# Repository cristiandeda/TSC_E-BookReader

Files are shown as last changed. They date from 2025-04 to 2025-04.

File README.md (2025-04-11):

# TSC_E-BookReader

## Diagrama bloc:
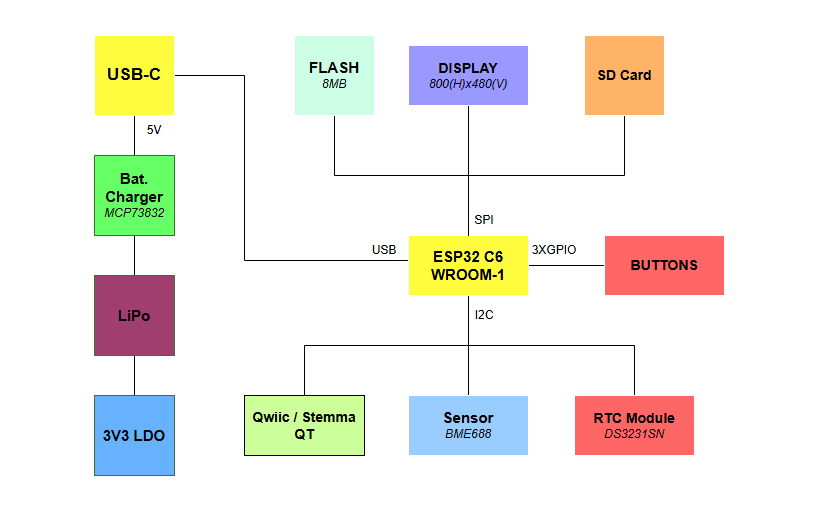
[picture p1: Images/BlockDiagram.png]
diagram


## Pasi de implementare:

- Am creat **schema electrica** pe baza celei atasate in cerinta, folosind biblioteca `DeskAssistant`
- Am creat apoi **PCB**-ul:
    - am modificat dimensiunile PCB-ului pentru a corespunde cu cele descrise in cerinta
    -  am plasat componentele in functie de schema electrica, grupandu-le pe baza 'functionalitatii'
    -  am decupat PCB-ul conform fisierului atasat in enunt
    -  am modificat denumirile *test-pad-urilor* - *TP* in functie de semnalele pe care le poarta
    -  am facut autorutare cu dimensiunile traseelor de alimentare precizate in enunt (`VBUS`, `VUSB`, `VBAT`, `3V3`, `EPD_3V3` si `EPD_3V3_C` cu *CopperWidth* de minimum **0.3 mm**, iar restul cu *CopperWidth* de minimum **0.15 mm**)
    -  am trasat planurile de masa (*top* si *bottom*)
- Am introdus modelele **3D**:
    - am descarcat modelele 3D corespunzatoare de pe [Component Search Engine](https://componentsearchengine.com/)
    - am editat fiecare componenta, adaugandu-i modelul 3D pe care l-am pozitionat conform *pinilor* / *footprint-ului*
- Am desenat modelele **3D** pentru *baterie*, *ecran* si *test-pad-uri* tinand cont de dimensiuni
- Am adaugat toate piesele (*placuta*, *ecranul*, *bateria* si *carcasa*) obtinand produsul final

## Descriere functionalitate hardware:

### 1. Alimentare și Protecție (USB-C & ESD)
- **Conector USB-C**: permite alimentarea plăcii și comunicarea de date.
- **PFMF.050.1**, **TVS diode (D1)**: oferă protecție la supratensiuni și descărcări electrostatice.
- **IC1**: convertește tensiunea de intrare (5V) la 3.3V, necesară pentru alimentarea circuitelor logice (ESP32, senzori, etc.).

### 2. Control Alimentare Baterie
- **MCP73831** este un controler de încărcare pentru baterii Li-Po.
- **C1, C2** filtrează zgomotele pe linia de alimentare.
- Permite alimentarea sistemului din baterie reîncărcabilă și oferă protecție la supraîncărcare/descărcare.

### 3. Nivel Încărcare Baterie
- **MAX17048** măsoară nivelul de încărcare al bateriei.
- Comunicarea se face prin magistrala I2C (SCL/SDA), comună cu alți senzori.
- Permite afișarea nivelului bateriei pe ecran sau transmiterea sa prin rețea.

### 4. Afișaj E-Paper
- **Header E-Paper** conectează un afișaj de tip E-Ink.
- **Driverul de semnal (MBR0530, L1, Q3)** controlează alimentarea și semnalele de comutare pentru afișaj.
- Selectarea tipului de ecran se face cu jumperul **S1**.
- Afișajul e-paper este ideal pentru consum redus de energie.

### 5. Modul RTC (Ceas în timp real)
- **DS3231SN** menține ora exactă, chiar și când placa este oprită.
- Funcționează pe I2C și are o baterie de rezervă.

### 6. Senzor Ambiental (BME688)
- Măsoară temperatură, umiditate, presiune și calitatea aerului.
- Se conectează la ESP32 prin I2C.

### 7. Memorie NOR Flash externă (64MB)
- **W25Q512JVEIQ** este o memorie SPI folosită pentru stocare extinsă (ex: cărți, imagini, date).
- Conectată la ESP32 pe interfață SPI (IO4–IO7).
- Permite stocarea persistentă a fișierelor.

### 8. Cititor Card SD
- Slot SD conectat prin SPI (IO8–IO11).
- Permite acces la fișiere externe, jurnalizare sau încărcare de date din card.

### 9. ESP32-C6 - Microcontroller Principal
- Conectează toate perifericele și controlează logica sistemului.
- Suportă Wi-Fi 6, BLE 5.2 și Zigbee/Thread.
- Are GPIO configurate pentru SPI, I2C, UART și control E-Paper.
- Este nucleul care rulează software-ul aplicației.

### 10. Protecții ESD pe SPI & Qwiic
- Diodă **TVS** și rezistențe pe liniile SPI/Qwiic pentru protecție la ESD.
- Asigură durabilitate mai mare în aplicații reale.

### 11. Butoane - Reset & Boot
- Buton **RESET**: Repornește ESP32.
- Buton **BOOT**: Permite intrarea în mod de boot pentru programare.
- Ambele conectate la pini critici (EN, IO0).

### 12. Interfață Qwiic / Stemma QT
- Conector I2C standard (JST-SH 4 pini).
- Permite adăugarea rapidă de senzori sau module adiționale compatibile.

### 13. Test Pads
- Paduri expuse pentru GPIO-uri esențiale.
- Permit depanarea, măsurători și extinderea funcționalității.

---

## Descrierea pinilor ESP32-C6:

| Pin ESP32-C6 | Nume Semnal | Componentă Asociată | Scop / Funcție |
|---|---|---|---|
| GND | GND | Toate componentele | Masă comună pentru alimentare și semnal. |
| EN | Enable | Buton Reset | Resetează microcontrollerul la apăsare. |
| IO0 | GPIO0 | Buton BOOT | Intrare în modul de boot la apăsare. |
| IO1 | GPIO1 | Test Pad TP11 | Test/debug sau I/O general. |
| IO2 | GPIO2 | Test Pad TP12 | Test/debug sau I/O general. |
| IO3 | GPIO3 | Test Pad TP13 | Test/debug sau I/O general. |
| IO4 | GPIO4 | SPI Flash (CS) | Chip Select pentru memoria NOR Flash externă. |
| IO5 | GPIO5 | SPI Flash (CLK) | Clock SPI pentru memoria NOR Flash externă. |
| IO6 | GPIO6 | SPI Flash (MISO) | Data Out din NOR Flash spre ESP32. |
| IO7 | GPIO7 | SPI Flash (MOSI) | Data In către NOR Flash de la ESP32. |
| IO8 | GPIO8 | SD Card (CS) | Chip Select pentru card SD. |
| IO9 | GPIO9 | SD Card (CLK) | Clock SPI pentru card SD. |
| IO10 | GPIO10 | SD Card (MISO) | Date de pe card SD către ESP32. |
| IO11 | GPIO11 | SD Card (MOSI) | Date de la ESP32 către card SD. |
| IO12 | GPIO12 | E-Paper Header | Semnal pentru ecran E-Paper (ex: BUSY, RST etc.). |
| IO13 | GPIO13 | E-Paper Header | Semnal pentru ecran E-Paper. |
| IO14 | GPIO14 | E-Paper Header | Semnal pentru ecran E-Paper. |
| IO15 | GPIO15 | E-Paper Header | Semnal pentru ecran E-Paper. |
| IO16 | GPIO16 | SCL (RTC & BME688) | I2C Clock comun pentru RTC și senzor de mediu. |
| IO17 | GPIO17 | SDA (RTC & BME688) | I2C Data comun pentru RTC și senzor de mediu. |
| IO18 | GPIO18 | UART_RX (Qwiic/Debug) | Recepție serială (debug sau Qwiic/StemMA). |
| IO19 | GPIO19 | UART_TX (Qwiic/Debug) | Transmisie serială (debug sau Qwiic/StemMA). |

## Bill of Materials (BOM):

| Componenta | Link | Datasheet |
|---|---|---|
| ESP32-C6-WROOM-1-N8 | [Link](https://ro.mouser.com/ProductDetail/Espressif-Systems/ESP32-C6-WROOM-1-N8?qs=8Wlm6%252BaMh8ST02Gmwp74cw%3D%3D) | [Datasheet](https://ro.mouser.com/datasheet/2/891/Espressif_ESP32_C6_WROOM_1__Datasheet_V0_1_PRELIMI-3239987.pdf) |
| 112A-TAAR-R03_ATTEND | [Link](https://www.digikey.ro/ro/products/detail/attend-technology/112A-TAAR-R03/17633923) | [Datasheet](https://www.attend.com.tw/data/download/file/112A-TAAR-R03_Spec.pdf) |
| ADAFRUIT_LEDCHIP-LED0603 | [Link](https://www.snapeda.com/parts/KP-1608SURCK/Kingbright/view-part/?ref=search&t=LED%200603) | [Datasheet](https://www.snapeda.com/parts/KP-1608SURCK/Kingbright/datasheet/) |
| ESP32_WROVER_EAGLE-LTSPICE_RR0402 | [Link](https://www.snapeda.com/parts/RC0402FR-07226RL/Yageo/view-part/) | [Datasheet](https://www.snapeda.com/parts/RC0402FR-07226RL/Yageo/datasheet/) |
| ESP32_WROVER_EAGLE-LTSPICE_CC0402 | [Link](https://componentsearchengine.com/part-view/CC0402MRX5R5BB106/YAGEO) | [Datasheet](https://componentsearchengine.com/Datasheets/2/CC0402MRX5R5BB106.pdf) |
| RCL_CPOL-EUCT3528 | [Link](https://ro.mouser.com/ProductDetail/Vishay-Sprague/TR3B106K025C1300?qs=jCGqFXxTmLdffnuDkXzk1g%3D%3D) | [Datasheet](https://www.vishay.com/docs/40080/tr3.pdf) |
| ESP32_WROVER_SPARKFUN-DISCRETESEMI_MOSFET_PCH-DMG2305UX-7 | [Link](https://ro.mouser.com/ProductDetail/Diodes-Incorporated/DMG2305UX-7?qs=L1DZKBg7t5F%2FNBHrjfxC%252Bg%3D%3D) | [Datasheet](https://www.diodes.com/assets/Datasheets/DMG2305UX.pdf) |
| 744043680IND_4828-WE-TPC_WRE | [Link](https://www.digikey.sg/en/products/detail/w%C3%BCrth-elektronik/744043680/1638515) | [Datasheet](https://www.we-online.com/components/products/datasheet/744043680.pdf) |
| BD5229G-TR | [Link](https://ro.mouser.com/ProductDetail/ROHM-Semiconductor/BD5229G-TR?qs=4kLU8WoGk0vvnhrrYwdszw%3D%3D) | [Datasheet](https://fscdn.rohm.com/en/products/databook/datasheet/ic/power/voltage_detector/bd52xxg-e.pdf) |
| ESP32_WROVER_BME680_BME680 | [Link](https://ro.mouser.com/ProductDetail/Bosch-Sensortec/BME680?qs=v271MhAjFHjo0yA%2FC4OnDQ%3D%3D) | [Datasheet](https://ro.mouser.com/datasheet/2/783/BST_BME680_DS001-1509608.pdf) |
| BUTTON_CUSYOMV1 | [Link](https://ro.mouser.com/ProductDetail/Panasonic/EVQ-P7M01P?qs=rJ%252BziJWpysz0sJAzuCybtw%3D%3D) | [Datasheet](https://industry.panasonic.com/global/en/downloads/?file_cd=402906&tab=catalog&series_cd=3457) |
| CPH3225A | [Link](https://ro.mouser.com/ProductDetail/Seiko-Semiconductors/CPH3225A?qs=3etwrb1wR%252BhUOph6lAO7eg%3D%3D) | [Datasheet](https://ro.mouser.com/datasheet/2/360/Seiko_Instruments_MicroBattery_E_20230330_2024Jan_-3561061.pdf) |
| DS3231SN# | [Link](https://ro.mouser.com/ProductDetail/Analog-Devices-Maxim-Integrated/DS3231SN?qs=1eQvB6Dk1vhUlr8%2FOrV0Fw%3D%3D) | [Datasheet](https://ro.mouser.com/datasheet/2/609/DS3231-3421123.pdf) |
| ESP32C6_VARISTORCN1812 | [Link](https://eu.mouser.com/ProductDetail/KEMET/VC1812L501R008?qs=jj7GbYRQuOa1j1%2F3gPpdvQ%3D%3D) | [Datasheet](https://eu.mouser.com/datasheet/2/447/KEM_V0002_VC-3316862.pdf) |
| ESP32_WROVER_AVX---SD0805S020S1R0_AVX_SD0805S020S1R0_0_0AVX_SD0805S020S1R0_0_0 | [Link](https://eu.mouser.com/ProductDetail/KYOCERA-AVX/SD0805S020S1R0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) | [Datasheet](https://eu.mouser.com/datasheet/2/40/schottky-3165252.pdf) |
| FH34SRJ-24S-0.5SH_99_ | [Link](https://eu.mouser.com/ProductDetail/Hirose-Connector/FH34SRJ-24S-05SH99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) | [Datasheet](https://eu.mouser.com/datasheet/2/185/FH34SRJ_24S_0_5SH_99__CL0580_1255_6_99_2DDrawing_0-1615044.pdf) |
| MAX17048G+T10 | [Link](https://eu.mouser.com/ProductDetail/Analog-Devices-Maxim-Integrated/MAX17048G+T10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) | [Datasheet](https://eu.mouser.com/datasheet/2/609/MAX17048_MAX17049-3469099.pdf) |
| MBR0530 | [Link](https://eu.mouser.com/ProductDetail/Micro-Commercial-Components-MCC/MBR0530-TP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) | [Datasheet](https://eu.mouser.com/datasheet/2/258/MBR0520_MBR0580_SOD123_-2492194.pdf) |
| ESP32_WROVER_SPARKFUN-IC-POWER_MCP73831 | [Link](https://ro.mouser.com/ProductDetail/Microchip-Technology/MCP73831-2DCI-MC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) | [Datasheet](https://ro.mouser.com/datasheet/2/268/MCP73831_Family_Data_Sheet_DS20001984H-3441711.pdf) |
| PGB1010603MR | [Link](https://ro.mouser.com/ProductDetail/Littelfuse/PGB1010603MR?qs=gu7KAQ731URLg4GSnNNN7Q%3D%3D) | [Datasheet](https://www.littelfuse.com/assetdocs/pulseguard-esd-suppressors-pgb1-datasheet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) |
| QWIIC_CONNECTORJS-1MM | [Link](https://www.sparkfun.com/qwiic-jst-connector-smd-4-pin-vertical.html) | [Datasheet](https://www.jst-mfg.com/product/pdf/eng/eSH.pdf?5ec58813d214e) |
| SAMACSYS_PARTS_USB4110-GF-A | [Link](https://eu.mouser.com/ProductDetail/GCT/USB4110-GF-A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) | [Datasheet](https://eu.mouser.com/datasheet/2/837/GCT_USB4110_Product_Drawing___20k_cycles-3455479.pdf) |
| SI1308EDL-T1-GE3 | [Link](https://eu.mouser.com/ProductDetail/Vishay-Semiconductors/SI1308EDL-T1-GE3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) | [Datasheet](https://www.vishay.com/docs/63399/si1308edl.pdf) |
| USBLC6-2SC6Y | [Link](https://eu.mouser.com/ProductDetail/STMicroelectronics/USBLC6-2SC6Y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) | [Datasheet](https://eu.mouser.com/datasheet/2/389/usblc6_2sc6y-1852505.pdf) |
| SJ | [Link](https://grabcad.com/library/solder-jumpers-1) | [Datasheet]() |
| W25Q512JVEIQ | [Link](https://eu.mouser.com/ProductDetail/Winbond/W25Q512JVEIQ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) | [Datasheet](https://eu.mouser.com/datasheet/2/949/Winbond_W25Q512JV_Datasheet-3240039.pdf) |
| XC6220A331MR-G | [Link](https://eu.mouser.com/ProductDetail/Torex-Semiconductor/XC6220A331MR-G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) | [Datasheet](https://eu.mouser.com/datasheet/2/760/xc6220-3371556.pdf) |

## Probleme:

- Am aprobat 2 erori tip *SMD-Hole* la rutarea *PCB-ului*
- Am aprobat erorile de tip *part X has no value* sau *pin X connected to Y* ce apareau dupa rularea *ERC-ului* in schematic
- Pentru *Test-pad-uri* am creat eu un model 3D cilindric, deoarece nu am gasit model pe internet

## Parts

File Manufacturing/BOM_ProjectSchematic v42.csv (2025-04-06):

Qty | Value | Device | Package | Parts | Description | ARROW_PART_NUMBER | ARROW_PRICE-STOCK | AVAILABILITY | CENTROID_NOT_SPECIFIED | CHECK_PRICES | COPYRIGHT | DATASHEET | DESCRIPTION | DIGIKEY_DESCRIPTION | DIGIKEY_PART_NUMBER | HEIGHT | LEAD_FREE | MANUFACTURER_NAME | MANUFACTURER_PART_NUMBER | MF | MFR_NAME | MOUSER_PART_NUMBER | MOUSER_PRICE-STOCK | MOUSER_TESTING_PART_NUMBER | MOUSER_TESTING_PRICE-STOCK | MP | MPN | PACKAGE | POPULARITY | PREFIX | PRICE | PROD_ID | PURCHASE-URL | ROHS | SNAPEDA_LINK | SPICEMODEL | SPICEPREFIX | TEMPERATURE_RANGE_HIGH | TEMPERATURE_RANGE_LOW | TP_SIGNAL_NAME | VALUE
1 |  | ADAFRUIT_LEDCHIP-LED0603 | ADAFRUIT_CHIP-LED0603 | CHG_LED | LED
1 |  | SJ | SJ | SJ1 | SMD solder JUMPER |  |  |  |  |  |  |  |  |  |  |  |  |  |  |  |  |  |  |  |  |  |  |  | 3
1 | 0.1uF/50V | ESP32_WROVER_EAGLE-LTSPICE_CC0402 | ESP32_WROVER_EAGLE-LTSPICE_C0402 | EPD_C5 | CAPACITOR, European symbol |  |  |  |  |  |  |  |  |  |  |  |  |  |  |  |  |  |  |  |  |  |  |  |  |  |  |  |  |  |  | NONE | C
1 | 0.47 | ESP32_WROVER_EAGLE-LTSPICE_RR0402 | ESP32_WROVER_EAGLE-LTSPICE_R0402 | R3 | RESISTOR, European symbol |  |  |  |  |  |  |  |  |  |  |  |  |  |  |  |  |  |  |  |  |  |  |  |  |  |  |  |  |  |  | NONE | R
1 | 100K | ESP32_WROVER_EAGLE-LTSPICE_RR0402 | ESP32_WROVER_EAGLE-LTSPICE_R0402 | R1_PWRUSB | RESISTOR, European symbol |  |  |  |  |  |  |  |  |  |  |  |  |  |  |  |  |  |  |  |  |  |  |  |  |  |  |  |  |  |  | NONE | R
8 | 100nF | ESP32_WROVER_EAGLE-LTSPICE_CC0402 | ESP32_WROVER_EAGLE-LTSPICE_C0402 | C1, C2, C4_USB, C6, C8, C9, C10, C_DELAY | CAPACITOR, European symbol |  |  |  |  |  |  |  |  |  |  |  |  |  |  |  |  |  |  |  |  |  |  |  |  |  |  |  |  |  |  | NONE | C
1 | 100uF TANT | RCL_CPOL-EUCT3528 | RCL_CT3528 | C3 | POLARIZED CAPACITOR, European symbol |  |  |  |  |  |  |  |  |  |  |  |  |  |  |  |  |  |  |  |  |  |  |  | 0 |  |  |  |  |  |  |  | C
16 | 10K | ESP32_WROVER_EAGLE-LTSPICE_RR0402 | ESP32_WROVER_EAGLE-LTSPICE_R0402 | R1, R1_PINH, R1_PINH1, R2-PINH, R2-PINH1, R4, R5, R6, R7, R8, R9, R10, R_BOOT, R_CHANGE, R_CL1, R_RESET | RESISTOR, European symbol |  |  |  |  |  |  |  |  |  |  |  |  |  |  |  |  |  |  |  |  |  |  |  |  |  |  |  |  |  |  | NONE | R
1 | 10uF | ESP32_WROVER_EAGLE-LTSPICE_CC0402 | ESP32_WROVER_EAGLE-LTSPICE_C0402 | C7 | CAPACITOR, European symbol |  |  |  |  |  |  |  |  |  |  |  |  |  |  |  |  |  |  |  |  |  |  |  |  |  |  |  |  |  |  | NONE | C
1 | 112A-TAAR-R03_ATTEND | 112A-TAAR-R03_ATTEND | 112ATAARR03ATTEND | J4 | Micro SD Card Socket, Push-Push Type, Top Mount, SMT, H=1.83mm, 10u |  |  |  |  |  |  |  | Micro SD Card Socket | Push-Push Type | Top Mount | SMT | H=1.83mm | 10u |  |  | 1.9mm |  | ATTEND | 112A-TAAR-R03 ATTEND
1 | 15 | ESP32_WROVER_EAGLE-LTSPICE_RR0402 | ESP32_WROVER_EAGLE-LTSPICE_R0402 | R_CAPACITOR | RESISTOR, European symbol |  |  |  |  |  |  |  |  |  |  |  |  |  |  |  |  |  |  |  |  |  |  |  |  |  |  |  |  |  |  | NONE | R
1 | 1uF | ESP32_WROVER_EAGLE-LTSPICE_CC0402 | ESP32_WROVER_EAGLE-LTSPICE_C0402 | C5 | CAPACITOR, European symbol |  |  |  |  |  |  |  |  |  |  |  |  |  |  |  |  |  |  |  |  |  |  |  |  |  |  |  |  |  |  | NONE | C
9 | 1uF/50V | ESP32_WROVER_EAGLE-LTSPICE_CC0402 | ESP32_WROVER_EAGLE-LTSPICE_C0402 | EPD_C1, EPD_C2, EPD_C6, EPD_C7, EPD_C8, EPD_C9, EPD_C10, EPD_C11, EPD_C12 | CAPACITOR, European symbol |  |  |  |  |  |  |  |  |  |  |  |  |  |  |  |  |  |  |  |  |  |  |  |  |  |  |  |  |  |  | NONE | C
1 | 2.2 | ESP32_WROVER_EAGLE-LTSPICE_RR0402 | ESP32_WROVER_EAGLE-LTSPICE_R0402 | R2 | RESISTOR, European symbol |  |  |  |  |  |  |  |  |  |  |  |  |  |  |  |  |  |  |  |  |  |  |  |  |  |  |  |  |  |  | NONE | R
1 | 200 | ESP32_WROVER_EAGLE-LTSPICE_RR0402 | ESP32_WROVER_EAGLE-LTSPICE_R0402 | R1_BAT | RESISTOR, European symbol |  |  |  |  |  |  |  |  |  |  |  |  |  |  |  |  |  |  |  |  |  |  |  |  |  |  |  |  |  |  | NONE | R
2 | 20V/4.2A/52mO/1.4W | ESP32_WROVER_SPARKFUN-DISCRETESEMI_MOSFET_PCH-DMG2305UX-7 | ESP32_WROVER_SPARKFUN-DISCRETESEMI_SOT23-3 | Q1, Q2 | P-channel MOSFETs |  |  |  |  |  |  |  |  |  |  |  |  |  |  |  |  |  |  |  |  |  |  |  |  |  |  | TRAN-14388 |  |  |  |  |  |  |  |  | 20V/4.2A/52mO/1.4W
1 | 2K | ESP32_WROVER_EAGLE-LTSPICE_RR0402 | ESP32_WROVER_EAGLE-LTSPICE_R0402 | R2_BAT | RESISTOR, European symbol |  |  |  |  |  |  |  |  |  |  |  |  |  |  |  |  |  |  |  |  |  |  |  |  |  |  |  |  |  |  | NONE | R
5 | 4.7uF | ESP32_WROVER_EAGLE-LTSPICE_CC0402 | ESP32_WROVER_EAGLE-LTSPICE_C0402 | C1_BAT, C1_BAT1, C1_BAT2, C2_BAT, C5_USB | CAPACITOR, European symbol |  |  |  |  |  |  |  |  |  |  |  |  |  |  |  |  |  |  |  |  |  |  |  |  |  |  |  |  |  |  | NONE | C
1 | 4.7uF/25V | ESP32_WROVER_EAGLE-LTSPICE_CC0402 | ESP32_WROVER_EAGLE-LTSPICE_C0402 | C4 | CAPACITOR, European symbol |  |  |  |  |  |  |  |  |  |  |  |  |  |  |  |  |  |  |  |  |  |  |  |  |  |  |  |  |  |  | NONE | C
1 | 5K1 | ESP32_WROVER_EAGLE-LTSPICE_RR0402 | ESP32_WROVER_EAGLE-LTSPICE_R0402 | R2-USB1 | RESISTOR, European symbol |  |  |  |  |  |  |  |  |  |  |  |  |  |  |  |  |  |  |  |  |  |  |  |  |  |  |  |  |  |  | NONE | R
1 | 5k1 | ESP32_WROVER_EAGLE-LTSPICE_RR0402 | ESP32_WROVER_EAGLE-LTSPICE_R0402 | R2-USB | RESISTOR, European symbol |  |  |  |  |  |  |  |  |  |  |  |  |  |  |  |  |  |  |  |  |  |  |  |  |  |  |  |  |  |  | NONE | R
1 | 68uH | 744043680IND_4828-WE-TPC_WRE | IND_4828-WE-TPC_WRE | L1 |  |  |  |  |  |  | Copyright (C) 2024 Ultra Librarian. All rights reserved. |  |  |  |  |  |  |  | 744043680 |  | Wurth Electronics
1 | BD5229G-TR | BD5229G-TR | SOT95P280X125-5N | IC1 | Voltage Detector with Adjustable Delay Time: CMOS processes are utilized to develop high precision, low current consumption CMOS reset ICs that allow arbitrary setting of the delay time. The extensive lineup includes both Nch Open Drain and CMOS output types in a wide range of detection voltages (from 2.3V to 6.0V, in 0.1V steps), enabling selection of the ideal solution based on customer requirements. In addition, the entire series is of course both lead-free and RoHS-compliant. |  |  |  |  |  |  |  | Voltage Detector with Adjustable Delay Time: CMOS processes are utilized to develop high precision | low current consumption CMOS reset ICs that allow arbitrary setting of the delay time. The extensive lineup includes both Nch Open Drain and CMOS output types in a wide range of detection voltages (from 2.3V to 6.0V | in 0.1V steps) | enabling selection of the ideal solution based on customer requirements. In addition | the entire series is of course both lead-free and RoHS-compliant. |  |  | 1.25mm |  | ROHM Semiconductor | BD5229G-TR |  |  | 755-BD5229G-TR | https://www.mouser.co.uk/ProductDetail/ROHM-Semiconductor/BD5229G-TR?qs=4kLU8WoGk0vvnhrrYwdszw%3D%3D
1 | BME688 | ESP32_WROVER_BME680_BME680 | ESP32_WROVER_BME680_PSON80P300X300X100-8N | SENSOR2 | Integrated Environmental Unit |  |  | Unavailable |  |  |  |  | Integrated Environmental Unit |  |  |  |  |  |  | Bosch Sensortec |  |  |  |  |  | BME680 |  | LGA-8 Bosch Tools |  |  | None
3 | BUTTON_CUSYOMV1 | BUTTON_CUSYOMV1 | MYBUTTON | BOOT_BUTTON, CHANGE_BUTTON, RESET_BUTTON
1 | CPH3225A | CPH3225A | CAPCP3225X100N | C10_SUPERCAP | Cap 0.011F 3.3V 1210 Flat Check availability |  |  | Not in stock |  | https://www.snapeda.com/parts/CPH3225A/Seiko+Instruments/view-part/?ref=eda |  |  | 11 mF (EDLC) Supercapacitor 3.3 V 1210 (3225 Metric) - - |  |  |  |  |  |  | Seiko Instruments |  |  |  |  |  | CPH3225A |  | 1210 Seiko |  |  | None |  | https://www.snapeda.com/api/url_track_click_mouser/?unipart_id=562593&manufacturer=Seiko Instruments&part_name=CPH3225A&search_term=None |  | https://www.snapeda.com/parts/CPH3225A/Seiko+Instruments/view-part/?ref=snap
1 | DS3231SN# | DS3231SN# | SOIC127P1032X265-16N | U3 | Real Time Clock Serial 16-Pin SOIC W T/R Check availability |  |  | In Stock |  | https://www.snapeda.com/parts/DS3231SN%23/Analog+Devices/view-part/?ref=eda |  |  | Extremely Accurate I²C-Integrated RTC/TCXO/Crystal |  |  |  |  |  |  | Analog Devices |  |  |  |  |  | DS3231SN# |  | SOIC-16 Maxim |  |  | None |  | https://www.snapeda.com/api/url_track_click_mouser/?unipart_id=99048&manufacturer=Analog Devices&part_name=DS3231SN#&search_term=None |  | https://www.snapeda.com/parts/DS3231SN%23/Analog+Devices/view-part/?ref=snap
1 | ESP32-C6-WROOM-1-N8 | ESP32-C6-WROOM-1-N8 | XCVR_ESP32-C6-WROOM-1-N8 | U2 | Check availability |  |  | In Stock |  | https://www.snapeda.com/parts/ESP32-C6-WROOM-1-N8/Espressif+Systems/view-part/?ref=eda |  |  | Multiprotocol Modules ESP32-C6 module | Wi-Fi 6 in 2.4 GHz band | Bluetooth 5 | Zigbee 3.0 and Thread. ESP34-WROOM Compatible - ENGINEERING SAMPLE |  |  |  |  |  |  | Espressif Systems |  |  |  |  |  | ESP32-C6-WROOM-1-N8 |  | None |  |  | None |  |  |  | https://www.snapeda.com/parts/ESP32-C6-WROOM-1-N8/Espressif+Systems/view-part/?ref=snap
1 | ESP32C6_VARISTORCN1812 | ESP32C6_VARISTORCN1812 | ESP32C6_VARISTOR_CT/CN1812 | PFMF.050.1 | VARISTOR |  |  |  |  |  |  |  |  |  |  |  |  |  |  |  |  |  |  |  |  |  |  |  | 0
2 | ESP32_WROVER_AVX---SD0805S020S1R0_AVX_SD0805S020S1R0_0_0AVX_SD0805S020S1R0_0_0 | ESP32_WROVER_AVX---SD0805S020S1R0_AVX_SD0805S020S1R0_0_0AVX_SD0805S020S1R0_0_0 | ESP32_WROVER_AVX---SD0805S020S1R0_AVX_SD0805S020S1R0_0 | D2, D7 | Schottky Barrier Rectifier Diode |  |  |  | No |  |  | http://datasheets.avx.com/schottky.pdf |  | DIODE SCHOTTKY 20V 1A 0805 | 478-7800-1-ND |  | yes |  |  | AVX |  | 581-SD0805S020S1R0 |  |  |  |  |  | 0805 (2012 metric) |  | D |  |  |  | yes |  |  |  | +125°C | -55°C
1 | FH34SRJ-24S-0.5SH_99_ | FH34SRJ-24S-0.5SH_99_ | FH34SRJ24S05SH99 | J1 | (0.50mm) Surface Mount, Right Angle |  |  |  |  |  |  |  | 24 Position FFC | FPC Connector Contacts | (0.50mm) Surface Mount | Right Angle |  |  | 1.1mm |  | Hirose | FH34SRJ-24S-0.5SH(99) |  |  | 798-FH34SRJ24S05SH99 | https://www.mouser.co.uk/ProductDetail/Hirose-Connector/FH34SRJ-24S-0.5SH99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
1 | MAX17048G+T10 | MAX17048G+T10 | SON50P200X200X80-9N | U4 | Check availability |  |  | In Stock |  | https://www.snapeda.com/parts/MAX17048G+T10/Analog+Devices/view-part/?ref=eda |  |  | 3µA 1-Cell/2-Cell Fuel Gauge with ModelGauge |  |  |  |  |  |  | Analog Devices |  |  |  |  |  | MAX17048G+T10 |  | TDFN-8 Maxim |  |  | None |  | https://www.snapeda.com/api/url_track_click_mouser/?unipart_id=329239&manufacturer=Analog Devices&part_name=MAX17048G+T10&search_term=None |  | https://www.snapeda.com/parts/MAX17048G+T10/Analog+Devices/view-part/?ref=snap
3 | MBR0530 | MBR0530 | SOD3716X135N | D3, D4, D5 | ON SEMICONDUCTOR - MBR0530 - DIODE, SCHOTTKY, 0.5A, 30V, SOD-123 |  |  | In Stock |  | https://www.snapeda.com/parts/MBR0530/Onsemi/view-part/?ref=eda |  |  | Diode Schottky 30 V 500mA Surface Mount SOD-123 |  |  |  |  |  |  | ON Semiconductor |  |  |  |  |  | MBR0530 |  | SOD-123-2 ON Semiconductor |  |  | None |  | https://www.snapeda.com/api/url_track_click_mouser/?unipart_id=179458&manufacturer=ON Semiconductor&part_name=MBR0530&search_term=None |  | https://www.snapeda.com/parts/MBR0530/Onsemi/view-part/?ref=snap
1 | MCP73831 | ESP32_WROVER_SPARKFUN-IC-POWER_MCP73831 | ESP32_WROVER_SPARKFUN-IC-POWER_SOT23-5 | U5 | MCP73831T Li-Ion, Li-Pol Controller |  |  |  |  |  |  |  |  |  |  |  |  |  |  |  |  |  |  |  |  |  |  |  |  |  |  | IC-09995
6 | PGB1010603MR | PGB1010603MR | DIOC1608X36N | D6, D8, D9, D10, D11, D12 | Check availability |  |  | In Stock |  | https://www.snapeda.com/parts/PGB1010603MR/Littelfuse/view-part/?ref=eda |  |  | 150V (Typ) Clamp - Ipp Tvs Diode Surface Mount 0603 (1608 Metric) |  |  |  |  |  |  | Littelfuse Inc. |  |  |  |  |  | PGB1010603MR |  | 0603 Littelfuse Inc. |  |  | None |  | https://www.snapeda.com/api/url_track_click_mouser/?unipart_id=5659453&manufacturer=Littelfuse Inc.&part_name=PGB1010603MR&search_term=None |  | https://www.snapeda.com/parts/PGB1010603MR/Littelfuse/view-part/?ref=snap
1 | QWIIC_RIGHT_ANGLE | QWIIC_CONNECTORJS-1MM | JST04_1MM_RA | J3 | SparkFun I2C Standard Qwiic Connector |  |  |  |  |  |  |  |  |  |  |  |  |  |  |  |  |  |  |  |  |  |  |  |  |  |  | CONN-13694 |  |  |  |  |  |  |  |  | QWIIC_RIGHT_ANGLE
1 | SAMACSYS_PARTS_USB4110-GF-A | SAMACSYS_PARTS_USB4110-GF-A | SAMACSYS_PARTS_USB4110GFA | J2 | CONN USB 2.0 TYPE-C R/A SMT |  |  |  |  |  |  |  | CONN USB 2.0 TYPE-C R/A SMT |  |  | 3.26mm |  | GCT (GLOBAL CONNECTOR TECHNOLOGY) | USB4110-GF-A |  |  | 640-USB4110-GF-A | https://www.mouser.co.uk/ProductDetail/GCT/USB4110-GF-A?qs=KUoIvG%2F9IlYiZvIXQjyJeA%3D%3D
1 | SI1308EDL-T1-GE3 | SI1308EDL-T1-GE3 | SOT65P210X110-3N | Q3 | MOSFET N-Ch 30V 1.5A TrenchFET SC70 Vishay Si1308EDL-T1-GE3 N-channel MOSFET Transistor, 1.5 A, 30 V, 3-Pin SC-70 |  |  | In Stock |  | https://www.snapeda.com/parts/SI1308EDL-T1-GE3/Vishay+Siliconix/view-part/?ref=eda |  |  | Si1308EDL-T1-GE3 N-channel MOSFET Transistor | 1.5 A | 30 V | 3-Pin SC-70 | Siliconix / Vishay SI1308EDL-T1-GE3 |  |  |  |  |  |  | Vishay Siliconix |  |  |  |  |  | SI1308EDL-T1-GE3 |  | SOT-323 Vishay Semiconductor |  |  | None |  | https://www.snapeda.com/api/url_track_click_mouser/?unipart_id=274603&manufacturer=Vishay Siliconix&part_name=SI1308EDL-T1-GE3&search_term=None |  | https://www.snapeda.com/parts/SI1308EDL-T1-GE3/Vishay+Siliconix/view-part/?ref=snap
17 | TPTP20R | TPTP20R | TP20R | 3V3, EPD_3V3, EPD_3V3_C, EPD_BUSY, EPD_CS, EPD_DC, EPD_RST, GND, GND_1, INT_RTC, MISO, MOSI, RX, SCK, TX, VBAT, VBUS | Test pad |  |  |  |  |  |  |  |  |  |  |  |  |  |  |  |  |  |  |  |  |  |  |  | 2
1 | USBLC6-2SC6Y | USBLC6-2SC6Y | SOT95P280X145-6N | D1 | Low Cap. ESD Protection Auto SOT-23-6 STMicroelectronics USBLC6-2SC6Y, Dual Uni-Directional TVS Diode Array, 6-Pin SOT-23 |  |  | In Stock |  | https://www.snapeda.com/parts/USBLC6-2SC6Y/STMicroelectronics/view-part/?ref=eda |  |  | 17V Clamp 5A (8/20µs) Ipp Tvs Diode Surface Mount SOT-23-6 |  |  |  |  |  |  | STMicroelectronics |  |  |  |  |  | USBLC6-2SC6Y |  | SOT-23-6 STMicroelectronics |  |  | None |  |  |  | https://www.snapeda.com/parts/USBLC6-2SC6Y/STMicroelectronics/view-part/?ref=snap
1 | W25Q512JVEIQ | W25Q512JVEIQ | SON127P600X800X80-9N | U1 | Check availability |  |  | In Stock |  | https://www.snapeda.com/parts/W25Q512JVEIQ/Winbond+Electronics/view-part/?ref=eda |  |  | FLASH - NOR Memory IC 512Mb (64M x 8) SPI - Quad I/O 133 MHz 8-WSON (8x6) |  |  |  |  |  |  | Winbond Electronics |  |  |  |  |  | W25Q512JVEIQ |  | Package |  |  | None |  |  |  | https://www.snapeda.com/parts/W25Q512JVEIQ/Winbond+Electronics/view-part/?ref=snap
1 | XC6220A331MR-G | XC6220A331MR-G | SOT95P280X120-5N | IC4 | LDO Voltage Regulators |  |  |  |  |  |  |  | LDO Voltage Regulators |  |  | 1.2mm |  | Torex | XC6220A331MR-G |  |  | 865-XC6220A331MR-G | https://www.mouser.co.uk/ProductDetail/Torex-Semiconductor/XC6220A331MR-G?qs=AsjdqWjXhJ8ZSWznL1J0gg%3D%3D

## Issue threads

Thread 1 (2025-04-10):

BOM Readme

DinuAndreiRazvan, 2025-04-10:
Componenta **BOM**(Bill of Materials) din Readme este prezentata sub formă de link catre un document Excel care contine informatii cu privire la componente. Trebuie extrase aceste date si formatate sub formă de tabel, in cadrul readme-ului, fiecare componenta cu informatiile si link-urile aferente acesteia.

cristiandeda, 2025-04-11:
Am adaugat BOM (Bill of Materials) sub forma de tabel. Multumesc!

Closed 2025-04-11.

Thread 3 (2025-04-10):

Erori ERC

DinuAndreiRazvan, 2025-04-10:
Prin rularea ERC-ului pentru verificarea schematicului apar 3 Warning-uri:
- 2 de Overlaping Pins
- 1 de Traseu Neconectat

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

cristiandeda, 2025-04-10:
Am rezolvat, multumesc!

Closed 2025-04-10.

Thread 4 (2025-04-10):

Valori si Nume componente PCB

DinuAndreiRazvan, 2025-04-10:
Valorile componentelor nu ar trbui sa apara pe PCB.

Numele componentelor ar trebui aranjate si scalate corespunzator pentru o mai buna lizibilitate a Silkscreen-ului.

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

cristiandeda, 2025-04-10:
Am remediat, multumesc!

Closed 2025-04-10.

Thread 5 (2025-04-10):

Trasee de Alimentare

DinuAndreiRazvan, 2025-04-10:
Lipsesc din clasa de traseelor de alimentare: V_USB+, V_USB-, VRTC si I2C_PW.

Acestea trebuiesc adaugate in aceasta clasa si configurate cu un CopperWidth de 0.3mm.

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

cristiandeda, 2025-04-10:
Le-am adaugat si am refacut traseele de alimentare, multumesc pentru observatie!

Closed 2025-04-10.

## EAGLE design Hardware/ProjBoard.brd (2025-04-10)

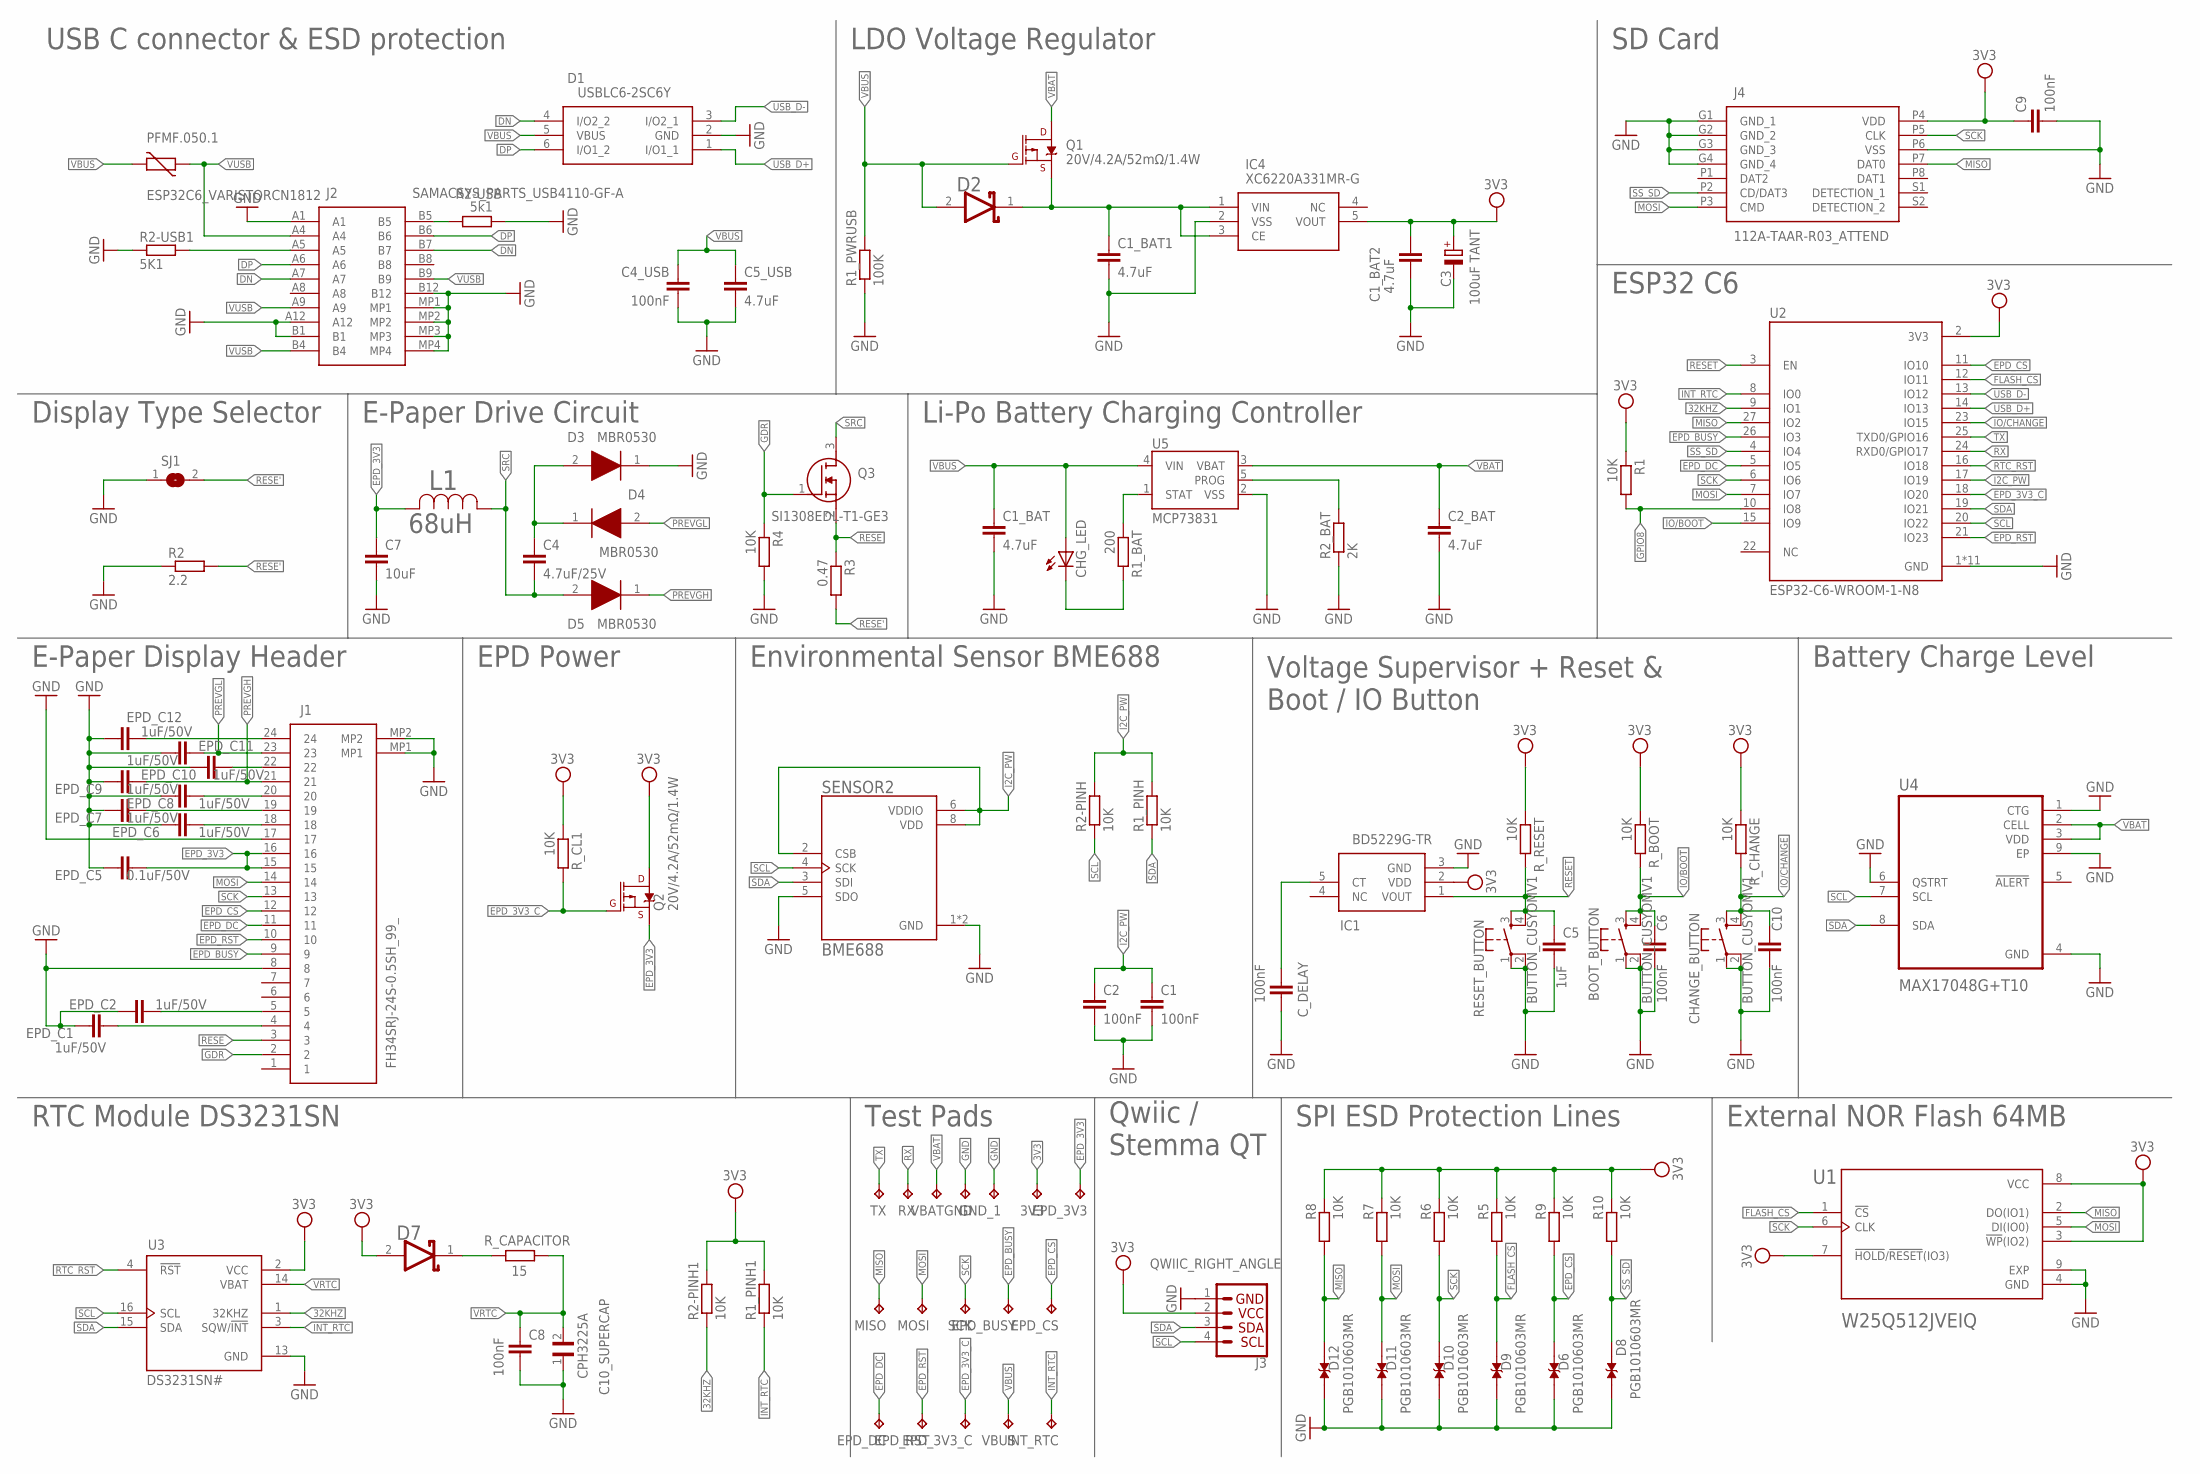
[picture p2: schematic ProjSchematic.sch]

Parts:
3V3: TPTP20R; TP20R
BOOT_BUTTON: BUTTON_CUSYOMV1; MYBUTTON
C1, C2, C4_USB, C6, C8, C9, C10: 100nF; ESP32_WROVER_EAGLE-LTSPICE_C0402
C1_BAT, C1_BAT1, C1_BAT2, C2_BAT, C5_USB: 4.7uF; ESP32_WROVER_EAGLE-LTSPICE_C0402
C3: 100uF TANT; RCL_CT3528
C4: 4.7uF/25V; ESP32_WROVER_EAGLE-LTSPICE_C0402
C5: 1uF; ESP32_WROVER_EAGLE-LTSPICE_C0402
C7: 10uF; ESP32_WROVER_EAGLE-LTSPICE_C0402
C10_SUPERCAP: CPH3225A; CAPCP3225X100N
CHANGE_BUTTON: BUTTON_CUSYOMV1; MYBUTTON
CHG_LED: ADAFRUIT_LEDCHIP-LED0603; ADAFRUIT_CHIP-LED0603
C_DELAY: 100nF; ESP32_WROVER_EAGLE-LTSPICE_C0402
D1: USBLC6-2SC6Y; SOT95P280X145-6N
D2, D7: ESP32_WROVER_AVX---SD0805S020S1R0_AVX_SD0805S020S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; ESP32_WROVER_AVX---SD0805S020S1R0_AVX_SD0805S020S1R0_0
D3, D4, D5: MBR0530; SOD3716X135N
D6, D8, D9, D10, D11, D12: PGB1010603MR; DIOC1608X36N
EPD_3V3, EPD_3V3_C: TPTP20R; TP20R
EPD_BUSY: TPTP20R; TP20R
EPD_C1, EPD_C2, EPD_C6, EPD_C7, EPD_C8, EPD_C9, EPD_C10, EPD_C11, EPD_C12: 1uF/50V; ESP32_WROVER_EAGLE-LTSPICE_C0402
EPD_C5: 0.1uF/50V; ESP32_WROVER_EAGLE-LTSPICE_C0402
EPD_CS: TPTP20R; TP20R
EPD_DC: TPTP20R; TP20R
EPD_RST: TPTP20R; TP20R
GND: TPTP20R; TP20R
GND_1: TPTP20R; TP20R
IC1: BD5229G-TR; SOT95P280X125-5N
IC4: XC6220A331MR-G; SOT95P280X120-5N
INT_RTC: TPTP20R; TP20R
J1: FH34SRJ-24S-0.5SH_99_; FH34SRJ24S05SH99
J2: SAMACSYS_PARTS_USB4110-GF-A; SAMACSYS_PARTS_USB4110GFA
J3: QWIIC_RIGHT_ANGLE; JST04_1MM_RA
J4: 112A-TAAR-R03_ATTEND; 112ATAARR03ATTEND
L1: 68uH; IND_4828-WE-TPC_WRE
MISO: TPTP20R; TP20R
MOSI: TPTP20R; TP20R
PFMF.050.1: ESP32C6_VARISTORCN1812; ESP32C6_VARISTOR_CT/CN1812
Q1, Q2: 20V/4.2A/52mΩ/1.4W; ESP32_WROVER_SPARKFUN-DISCRETESEMI_SOT23-3
Q3: SI1308EDL-T1-GE3; SOT65P210X110-3N
R1, R1_PINH, R1_PINH1, R2-PINH, R2-PINH1, R4, R5, R6, R7, R8, R9, R10: 10K; ESP32_WROVER_EAGLE-LTSPICE_R0402
R1_BAT: 200; ESP32_WROVER_EAGLE-LTSPICE_R0402
R1_PWRUSB: 100K; ESP32_WROVER_EAGLE-LTSPICE_R0402
R2: 2.2; ESP32_WROVER_EAGLE-LTSPICE_R0402
R2-USB: 5k1; ESP32_WROVER_EAGLE-LTSPICE_R0402
R2-USB1: 5K1; ESP32_WROVER_EAGLE-LTSPICE_R0402
R2_BAT: 2K; ESP32_WROVER_EAGLE-LTSPICE_R0402
R3: 0.47; ESP32_WROVER_EAGLE-LTSPICE_R0402
RESET_BUTTON: BUTTON_CUSYOMV1; MYBUTTON
RX: TPTP20R; TP20R
R_BOOT: 10K; ESP32_WROVER_EAGLE-LTSPICE_R0402
R_CAPACITOR: 15; ESP32_WROVER_EAGLE-LTSPICE_R0402
R_CHANGE: 10K; ESP32_WROVER_EAGLE-LTSPICE_R0402
R_CL1: 10K; ESP32_WROVER_EAGLE-LTSPICE_R0402
R_RESET: 10K; ESP32_WROVER_EAGLE-LTSPICE_R0402
SCK: TPTP20R; TP20R
SENSOR2: BME688; ESP32_WROVER_BME680_PSON80P300X300X100-8N
SJ1: SJ
TX: TPTP20R; TP20R
U1: W25Q512JVEIQ; SON127P600X800X80-9N
U2: ESP32-C6-WROOM-1-N8; XCVR_ESP32-C6-WROOM-1-N8
U3: DS3231SN#; SOIC127P1032X265-16N
U4: MAX17048G+T10; SON50P200X200X80-9N
U5: MCP73831; ESP32_WROVER_SPARKFUN-IC-POWER_SOT23-5
VBAT: TPTP20R; TP20R
VBUS: TPTP20R; TP20R

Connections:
3V3: 3V3.TP, C1_BAT2.1, C3.+, C9.1, D7.2 (ANODE), IC1.2 (VDD), IC4.5 (VOUT), J3.2, J4.P4 (VDD), Q2.3 (D), R1.1, R1_PINH1.2, R2-PINH1.2, R5.2, R6.2, R7.2, R8.2, R9.2, R10.2, R_BOOT.1, R_CHANGE.1, R_CL1.1, R_RESET.1, U1.3 (!WP!(IO2)), U1.7 (!HOLD!/!RESET!(IO3)), U1.8 (VCC), U2.2 (3V3), U3.2 (VCC)
32KHZ: R2-PINH1.1, U2.9 (IO1), U3.1 (32KHZ)
DN: D1.4 (I/O2_2), J2.A7, J2.B7
DP: D1.6 (I/O1_2), J2.A6, J2.B6
EPD_3V3: C7.1, EPD_3V3.TP, EPD_C5.2, J1.15, J1.16, L1.2, Q2.2 (S)
EPD_3V3_C: EPD_3V3_C.TP, Q2.1 (G), R_CL1.2, U2.18 (IO20)
EPD_BUSY: EPD_BUSY.TP, J1.9, U2.26 (IO3)
EPD_CS: D6.2, EPD_CS.TP, J1.12, R9.1, U2.11 (IO10)
EPD_DC: EPD_DC.TP, J1.11, U2.5 (IO5)
EPD_RST: EPD_RST.TP, J1.10, U2.21 (IO23)
FLASH_CS: D9.2, R5.1, U1.1 (!CS), U2.12 (IO11)
GDR: J1.2, Q3.1 (G), R4.1
GND: BOOT_BUTTON.1, BOOT_BUTTON.2, C1.2, C1_BAT.2, C1_BAT1.2, C1_BAT2.2, C2.2, C2_BAT.2, C3.-, C4_USB.2, C5.2, C5_USB.2, C6.2, C7.2, C8.2, C9.2, C10.2, C10_SUPERCAP.1, CHANGE_BUTTON.1, CHANGE_BUTTON.2, C_DELAY.2, D1.2 (GND), D3.1 (K), D6.1, D8.1, D9.1, D10.1, D11.1, D12.1, EPD_C1.2, EPD_C2.2, EPD_C5.1, EPD_C6.1, EPD_C7.1, EPD_C8.1, EPD_C9.1, EPD_C10.1, EPD_C11.1, EPD_C12.1, GND.TP, GND_1.TP, IC1.3 (GND), IC4.2 (VSS), J1.8, J1.17, J1.MP1, J1.MP2, J2.A1, J2.A12, J2.B1, J2.B12, J2.MP1, J2.MP2, J2.MP3, J2.MP4, J3.1, J4.G1 (GND_1), J4.G2 (GND_2), J4.G3 (GND_3), J4.G4 (GND_4), J4.P6 (VSS), R1_PWRUSB.1, R2.1, R2-USB.2, R2-USB1.1, R2_BAT.1, R4.2, RESET_BUTTON.1, RESET_BUTTON.2, SENSOR2.1 (GND), SENSOR2.5 (SDO), SENSOR2.7 (GND), SJ1.1, U1.4 (GND), U1.9 (EXP), U2.1 (GND), U2.28 (GND), U2.29_1 (GND), U2.29_2 (GND), U2.29_3 (GND), U2.29_4 (GND), U2.29_5 (GND), U2.29_6 (GND), U2.29_7 (GND), U2.29_8 (GND), U2.29_9 (GND), U3.13 (GND), U4.1 (CTG), U4.4 (GND), U4.6 (QSTRT), U4.9 (EP), U5.2 (VSS)
GPIO8: R1.2, U2.10 (IO8)
I2C_PW: C1.1, C2.1, R1_PINH.2, R2-PINH.2, SENSOR2.2 (CSB), SENSOR2.6 (VDDIO), SENSOR2.8 (VDD), U2.17 (IO19)
INT_RTC: INT_RTC.TP, R1_PINH1.1, U2.8 (IO0), U3.3 (SQW/!INT)
IO/BOOT: BOOT_BUTTON.3, BOOT_BUTTON.4, C6.1, R_BOOT.2, U2.15 (IO9)
IO/CHANGE: C10.1, CHANGE_BUTTON.3, CHANGE_BUTTON.4, R_CHANGE.2, U2.23 (IO15)
MISO: D12.2, J4.P7 (DAT0), MISO.TP, R8.1, U1.2 (DO(IO1)), U2.27 (IO2)
MOSI: D11.2, J1.14, J4.P3 (CMD), MOSI.TP, R7.1, U1.5 (DI(IO0)), U2.7 (IO7)
unnamed: J2.B5, R2-USB.1
unnamed: J2.A5, R2-USB1.2
unnamed: C1_BAT1.1, D2.1 (CATHODE), IC4.1 (VIN), IC4.3 (CE), Q1.2 (S)
unnamed: C4.1, D3.2 (A), D4.1 (K)
unnamed: CHG_LED.C, R1_BAT.2
unnamed: R1_BAT.1, U5.1 (STAT)
unnamed: EPD_C10.2, J1.22
unnamed: R2_BAT.2, U5.5 (PROG)
unnamed: C_DELAY.1, IC1.5 (CT)
unnamed: EPD_C1.1, J1.4
unnamed: EPD_C2.1, J1.5
unnamed: D7.1 (CATHODE), R_CAPACITOR.2
unnamed: EPD_C6.2, J1.18
unnamed: EPD_C7.2, J1.19
unnamed: EPD_C8.2, J1.20
unnamed: EPD_C12.2, J1.24
PREVGH: D5.1 (K), EPD_C9.2, J1.21
PREVGL: D4.2 (A), EPD_C11.2, J1.23
RESE: J1.3, Q3.2 (S), R3.1
RESE': R2.2, R3.2, SJ1.2
RESET: C5.1, IC1.1 (VOUT), RESET_BUTTON.3, RESET_BUTTON.4, R_RESET.2, U2.3 (EN)
RTC_RST: U2.16 (IO18), U3.4 (!RST)
RX: RX.TP, U2.24 (RXD0/GPIO17)
SCK: D10.2, J1.13, J4.P5 (CLK), R6.1, SCK.TP, U1.6 (CLK), U2.6 (IO6)
SCL: J3.4, R2-PINH.1, SENSOR2.4 (SCK), U2.20 (IO22), U3.16 (SCL), U4.7 (SCL)
SDA: J3.3, R1_PINH.1, SENSOR2.3 (SDI), U2.19 (IO21), U3.15 (SDA), U4.8 (SDA)
SRC: C4.2, D5.2 (A), L1.1, Q3.3 (D)
SS_SD: D8.2, J4.P2 (CD/DAT3), R10.1, U2.4 (IO4)
TX: TX.TP, U2.25 (TXD0/GPIO16)
USB_D+: D1.1 (I/O1_1), U2.14 (IO13)
USB_D-: D1.3 (I/O2_1), U2.13 (IO12)
VBAT: C2_BAT.1, Q1.3 (D), U4.2 (CELL), U4.3 (VDD), U5.3 (VBAT), VBAT.TP
VBUS: C1_BAT.1, C4_USB.1, C5_USB.1, CHG_LED.A, D1.5 (VBUS), D2.2 (ANODE), PFMF.050.1.2, Q1.1 (G), R1_PWRUSB.2, U5.4 (VIN), VBUS.TP
VRTC: C8.1, C10_SUPERCAP.2, R_CAPACITOR.1, U3.14 (VBAT)
VUSB: J2.A4, J2.A9, J2.B4, J2.B9, PFMF.050.1.1

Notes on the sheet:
USB C connector & ESD protection
LDO Voltage Regulator
SD Card
Display Type Selector
E-Paper Drive Circuit
Li-Po Battery Charging Controller
ESP32 C6
E-Paper Display Header
EPD Power
Environmental Sensor BME688
Voltage Supervisor + Reset & Boot / IO Button
Battery Charge Level
External NOR Flash 64MB
SPI ESD Protection Lines
Qwiic / Stemma QT
Test Pads
RTC Module DS3231SN

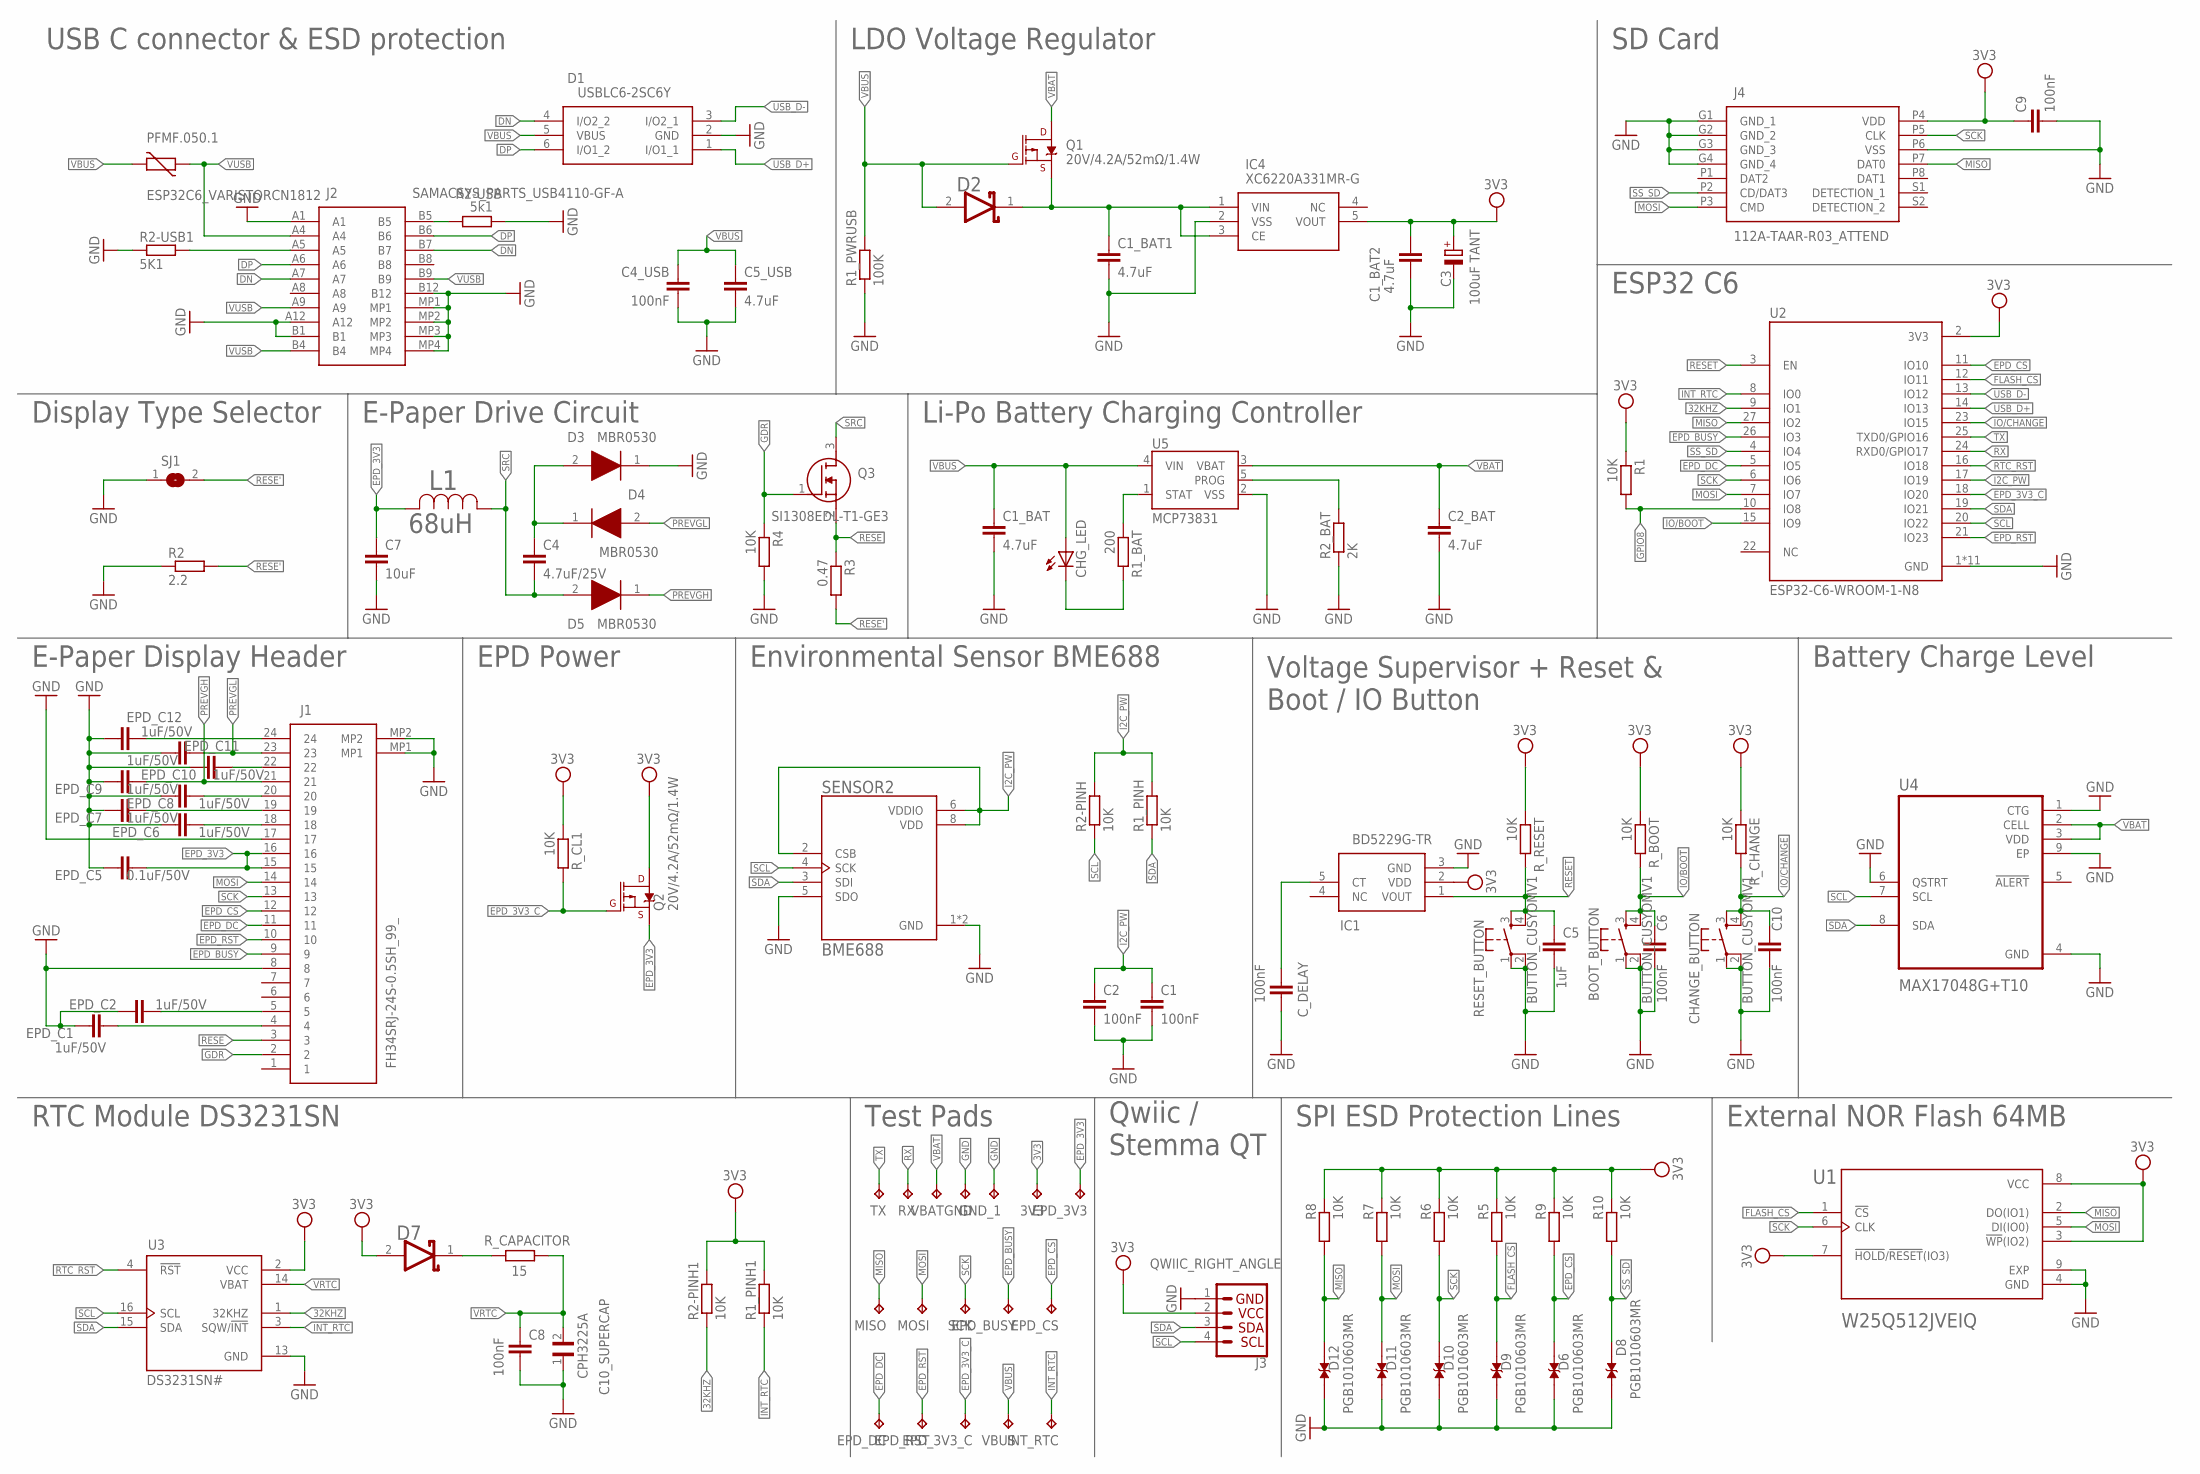
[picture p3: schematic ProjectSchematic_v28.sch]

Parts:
3V3: TPTP20R; TP20R
BOOT_BUTTON: BUTTON_CUSYOMV1; MYBUTTON
C1, C2, C4_USB, C6, C8, C9, C10: 100nF; ESP32_WROVER_EAGLE-LTSPICE_C0402
C1_BAT, C1_BAT1, C1_BAT2, C2_BAT, C5_USB: 4.7uF; ESP32_WROVER_EAGLE-LTSPICE_C0402
C3: 100uF TANT; RCL_CT3528
C4: 4.7uF/25V; ESP32_WROVER_EAGLE-LTSPICE_C0402
C5: 1uF; ESP32_WROVER_EAGLE-LTSPICE_C0402
C7: 10uF; ESP32_WROVER_EAGLE-LTSPICE_C0402
C10_SUPERCAP: CPH3225A; CAPCP3225X100N
CHANGE_BUTTON: BUTTON_CUSYOMV1; MYBUTTON
CHG_LED: ADAFRUIT_LEDCHIP-LED0603; ADAFRUIT_CHIP-LED0603
C_DELAY: 100nF; ESP32_WROVER_EAGLE-LTSPICE_C0402
D1: USBLC6-2SC6Y; SOT95P280X145-6N
D2, D7: ESP32_WROVER_AVX---SD0805S020S1R0_AVX_SD0805S020S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; ESP32_WROVER_AVX---SD0805S020S1R0_AVX_SD0805S020S1R0_0
D3, D4, D5: MBR0530; SOD3716X135N
D6, D8, D9, D10, D11, D12: PGB1010603MR; DIOC1608X36N
EPD_3V3, EPD_3V3_C: TPTP20R; TP20R
EPD_BUSY: TPTP20R; TP20R
EPD_C1, EPD_C2, EPD_C6, EPD_C7, EPD_C8, EPD_C9, EPD_C10, EPD_C11, EPD_C12: 1uF/50V; ESP32_WROVER_EAGLE-LTSPICE_C0402
EPD_C5: 0.1uF/50V; ESP32_WROVER_EAGLE-LTSPICE_C0402
EPD_CS: TPTP20R; TP20R
EPD_DC: TPTP20R; TP20R
EPD_RST: TPTP20R; TP20R
GND: TPTP20R; TP20R
GND_1: TPTP20R; TP20R
IC1: BD5229G-TR; SOT95P280X125-5N
IC4: XC6220A331MR-G; SOT95P280X120-5N
INT_RTC: TPTP20R; TP20R
J1: FH34SRJ-24S-0.5SH_99_; FH34SRJ24S05SH99
J2: SAMACSYS_PARTS_USB4110-GF-A; SAMACSYS_PARTS_USB4110GFA
J3: QWIIC_RIGHT_ANGLE; JST04_1MM_RA
J4: 112A-TAAR-R03_ATTEND; 112ATAARR03ATTEND
L1: 68uH; IND_4828-WE-TPC_WRE
MISO: TPTP20R; TP20R
MOSI: TPTP20R; TP20R
PFMF.050.1: ESP32C6_VARISTORCN1812; ESP32C6_VARISTOR_CT/CN1812
Q1, Q2: 20V/4.2A/52mΩ/1.4W; ESP32_WROVER_SPARKFUN-DISCRETESEMI_SOT23-3
Q3: SI1308EDL-T1-GE3; SOT65P210X110-3N
R1, R1_PINH, R1_PINH1, R2-PINH, R2-PINH1, R4, R5, R6, R7, R8, R9, R10: 10K; ESP32_WROVER_EAGLE-LTSPICE_R0402
R1_BAT: 200; ESP32_WROVER_EAGLE-LTSPICE_R0402
R1_PWRUSB: 100K; ESP32_WROVER_EAGLE-LTSPICE_R0402
R2: 2.2; ESP32_WROVER_EAGLE-LTSPICE_R0402
R2-USB: 5k1; ESP32_WROVER_EAGLE-LTSPICE_R0402
R2-USB1: 5K1; ESP32_WROVER_EAGLE-LTSPICE_R0402
R2_BAT: 2K; ESP32_WROVER_EAGLE-LTSPICE_R0402
R3: 0.47; ESP32_WROVER_EAGLE-LTSPICE_R0402
RESET_BUTTON: BUTTON_CUSYOMV1; MYBUTTON
RX: TPTP20R; TP20R
R_BOOT: 10K; ESP32_WROVER_EAGLE-LTSPICE_R0402
R_CAPACITOR: 15; ESP32_WROVER_EAGLE-LTSPICE_R0402
R_CHANGE: 10K; ESP32_WROVER_EAGLE-LTSPICE_R0402
R_CL1: 10K; ESP32_WROVER_EAGLE-LTSPICE_R0402
R_RESET: 10K; ESP32_WROVER_EAGLE-LTSPICE_R0402
SCK: TPTP20R; TP20R
SENSOR2: BME688; ESP32_WROVER_BME680_PSON80P300X300X100-8N
SJ1: SJ
TX: TPTP20R; TP20R
U1: W25Q512JVEIQ; SON127P600X800X80-9N
U2: ESP32-C6-WROOM-1-N8; XCVR_ESP32-C6-WROOM-1-N8
U3: DS3231SN#; SOIC127P1032X265-16N
U4: MAX17048G+T10; SON50P200X200X80-9N
U5: MCP73831; ESP32_WROVER_SPARKFUN-IC-POWER_SOT23-5
VBAT: TPTP20R; TP20R
VBUS: TPTP20R; TP20R

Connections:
3V3: 3V3.TP, C1_BAT2.1, C3.+, C9.1, D7.2 (ANODE), IC1.2 (VDD), IC4.5 (VOUT), J3.2, J4.P4 (VDD), Q2.3 (D), R1.1, R1_PINH1.2, R2-PINH1.2, R5.2, R6.2, R7.2, R8.2, R9.2, R10.2, R_BOOT.1, R_CHANGE.1, R_CL1.1, R_RESET.1, U1.3 (!WP!(IO2)), U1.7 (!HOLD!/!RESET!(IO3)), U1.8 (VCC), U2.2 (3V3), U3.2 (VCC)
32KHZ: R2-PINH1.1, U2.9 (IO1), U3.1 (32KHZ)
DN: D1.4 (I/O2_2), J2.A7, J2.B7
DP: D1.6 (I/O1_2), J2.A6, J2.B6
EPD_3V3: C7.1, EPD_3V3.TP, EPD_C5.2, J1.15, J1.16, L1.2, Q2.2 (S)
EPD_3V3_C: EPD_3V3_C.TP, Q2.1 (G), R_CL1.2, U2.18 (IO20)
EPD_BUSY: EPD_BUSY.TP, J1.9, U2.26 (IO3)
EPD_CS: D6.2, EPD_CS.TP, J1.12, R9.1, U2.11 (IO10)
EPD_DC: EPD_DC.TP, J1.11, U2.5 (IO5)
EPD_RST: EPD_RST.TP, J1.10, U2.21 (IO23)
FLASH_CS: D9.2, R5.1, U1.1 (!CS), U2.12 (IO11)
GDR: J1.2, Q3.1 (G), R4.1
GND: BOOT_BUTTON.1, BOOT_BUTTON.2, C1.2, C1_BAT.2, C1_BAT1.2, C1_BAT2.2, C2.2, C2_BAT.2, C3.-, C4_USB.2, C5.2, C5_USB.2, C6.2, C7.2, C8.2, C9.2, C10.2, C10_SUPERCAP.1, CHANGE_BUTTON.1, CHANGE_BUTTON.2, C_DELAY.2, D1.2 (GND), D3.1 (K), D6.1, D8.1, D9.1, D10.1, D11.1, D12.1, EPD_C1.2, EPD_C2.2, EPD_C5.1, EPD_C6.1, EPD_C7.1, EPD_C8.1, EPD_C9.1, EPD_C10.1, EPD_C11.1, EPD_C12.1, GND.TP, GND_1.TP, IC1.3 (GND), IC4.2 (VSS), J1.8, J1.17, J1.MP1, J1.MP2, J2.A1, J2.A12, J2.B1, J2.B12, J2.MP1, J2.MP2, J2.MP3, J2.MP4, J3.1, J4.G1 (GND_1), J4.G2 (GND_2), J4.G3 (GND_3), J4.G4 (GND_4), J4.P6 (VSS), R1_PWRUSB.1, R2.1, R2-USB.2, R2-USB1.1, R2_BAT.1, R4.2, RESET_BUTTON.1, RESET_BUTTON.2, SENSOR2.1 (GND), SENSOR2.5 (SDO), SENSOR2.7 (GND), SJ1.1, U1.4 (GND), U1.9 (EXP), U2.1 (GND), U2.28 (GND), U2.29_1 (GND), U2.29_2 (GND), U2.29_3 (GND), U2.29_4 (GND), U2.29_5 (GND), U2.29_6 (GND), U2.29_7 (GND), U2.29_8 (GND), U2.29_9 (GND), U3.13 (GND), U4.1 (CTG), U4.4 (GND), U4.6 (QSTRT), U4.9 (EP), U5.2 (VSS)
GPIO8: R1.2, U2.10 (IO8)
I2C_PW: C1.1, C2.1, R1_PINH.2, R2-PINH.2, SENSOR2.2 (CSB), SENSOR2.6 (VDDIO), SENSOR2.8 (VDD), U2.17 (IO19)
INT_RTC: INT_RTC.TP, R1_PINH1.1, U2.8 (IO0), U3.3 (SQW/!INT)
IO/BOOT: BOOT_BUTTON.3, BOOT_BUTTON.4, C6.1, R_BOOT.2, U2.15 (IO9)
IO/CHANGE: C10.1, CHANGE_BUTTON.3, CHANGE_BUTTON.4, R_CHANGE.2, U2.23 (IO15)
MISO: D12.2, J4.P7 (DAT0), MISO.TP, R8.1, U1.2 (DO(IO1)), U2.27 (IO2)
MOSI: D11.2, J1.14, J4.P3 (CMD), MOSI.TP, R7.1, U1.5 (DI(IO0)), U2.7 (IO7)
unnamed: J2.B5, R2-USB.1
unnamed: J2.A5, R2-USB1.2
unnamed: C1_BAT1.1, D2.1 (CATHODE), IC4.1 (VIN), IC4.3 (CE), Q1.2 (S)
unnamed: C4.1, D3.2 (A), D4.1 (K)
unnamed: CHG_LED.C, R1_BAT.2
unnamed: R1_BAT.1, U5.1 (STAT)
unnamed: EPD_C10.2, J1.22
unnamed: R2_BAT.2, U5.5 (PROG)
unnamed: C_DELAY.1, IC1.5 (CT)
unnamed: EPD_C1.1, J1.4
unnamed: EPD_C2.1, J1.5
unnamed: D7.1 (CATHODE), R_CAPACITOR.2
unnamed: EPD_C6.2, J1.18
unnamed: EPD_C7.2, J1.19
unnamed: EPD_C8.2, J1.20
unnamed: EPD_C12.2, J1.24
PREVGH: D5.1 (K), EPD_C9.2, J1.21
PREVGL: D4.2 (A), EPD_C11.2, J1.23
RESE: J1.3, Q3.2 (S), R3.1
RESE': R2.2, R3.2, SJ1.2
RESET: C5.1, IC1.1 (VOUT), RESET_BUTTON.3, RESET_BUTTON.4, R_RESET.2, U2.3 (EN)
RTC_RST: U2.16 (IO18), U3.4 (!RST)
RX: RX.TP, U2.24 (RXD0/GPIO17)
SCK: D10.2, J1.13, J4.P5 (CLK), R6.1, SCK.TP, U1.6 (CLK), U2.6 (IO6)
SCL: J3.4, R2-PINH.1, SENSOR2.4 (SCK), U2.20 (IO22), U3.16 (SCL), U4.7 (SCL)
SDA: J3.3, R1_PINH.1, SENSOR2.3 (SDI), U2.19 (IO21), U3.15 (SDA), U4.8 (SDA)
SRC: C4.2, D5.2 (A), L1.1, Q3.3 (D)
SS_SD: D8.2, J4.P2 (CD/DAT3), R10.1, U2.4 (IO4)
TX: TX.TP, U2.25 (TXD0/GPIO16)
USB_D+: D1.1 (I/O1_1), U2.14 (IO13)
USB_D-: D1.3 (I/O2_1), U2.13 (IO12)
VBAT: C2_BAT.1, Q1.3 (D), U4.2 (CELL), U4.3 (VDD), U5.3 (VBAT), VBAT.TP
VBUS: C1_BAT.1, C4_USB.1, C5_USB.1, CHG_LED.A, D1.5 (VBUS), D2.2 (ANODE), PFMF.050.1.2, Q1.1 (G), R1_PWRUSB.2, U5.4 (VIN), VBUS.TP
VRTC: C8.1, C10_SUPERCAP.2, R_CAPACITOR.1, U3.14 (VBAT)
VUSB: J2.A4, J2.A9, J2.B4, J2.B9, PFMF.050.1.1

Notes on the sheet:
USB C connector & ESD protection
LDO Voltage Regulator
SD Card
Display Type Selector
E-Paper Drive Circuit
Li-Po Battery Charging Controller
ESP32 C6
E-Paper Display Header
EPD Power
Environmental Sensor BME688
Voltage Supervisor + Reset & Boot / IO Button
Battery Charge Level
External NOR Flash 64MB
SPI ESD Protection Lines
Qwiic / Stemma QT
Test Pads
RTC Module DS3231SN

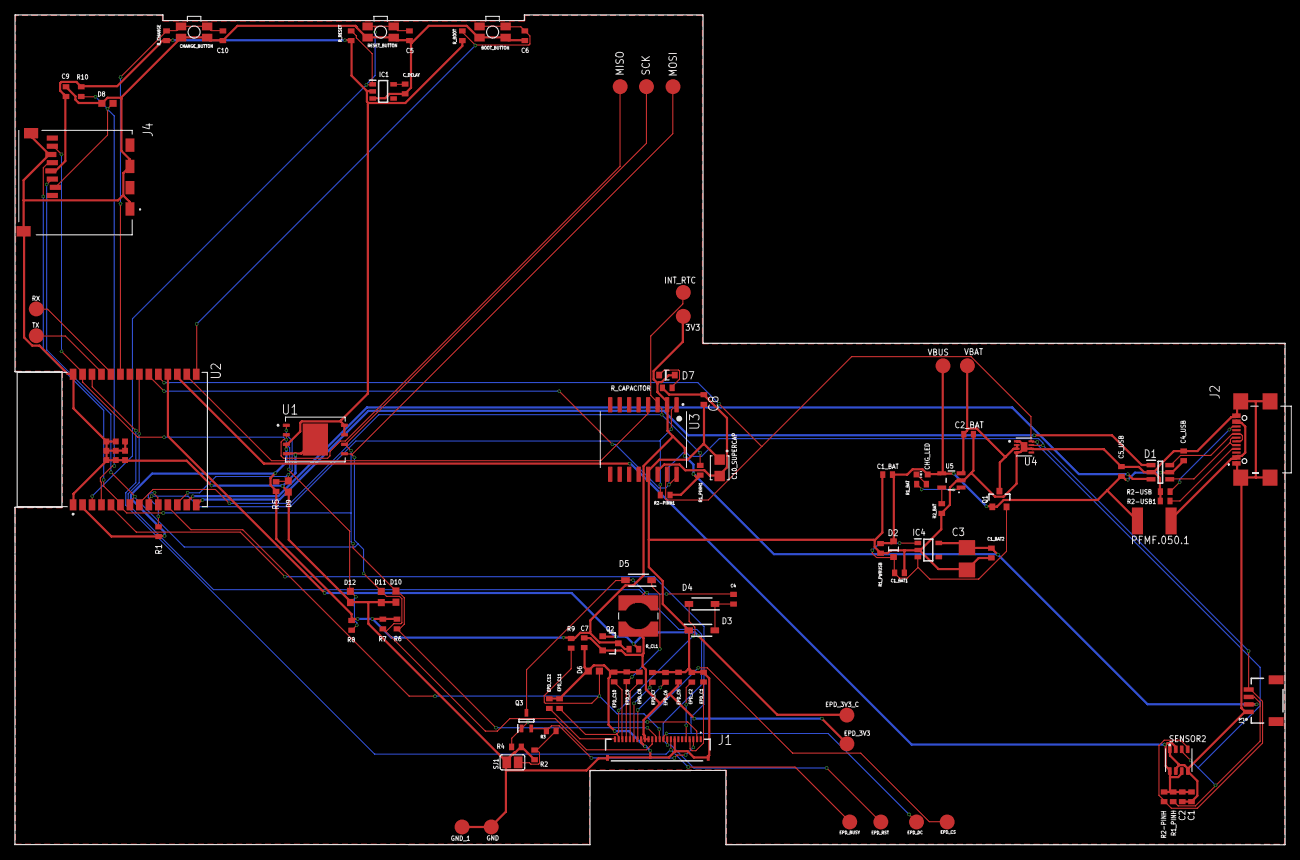
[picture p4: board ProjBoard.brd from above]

Board: 2 copper layers, 170.2 x 111.2 mm, 103 parts (0 on the bottom side), 55 nets.

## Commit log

2025-04-06 Added project files
    [BOM_ProjectSchematic v36.csv, PnP_ProjectSchematic v36_front.csv, ProjectSchematic v36.brd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]
2025-04-10 [Update schematic] - solved some errors
    [ProjSchematic.sch]
2025-04-10 [Update board] - solved some errors
    [ProjBoard.brd, ProjectSchematic v36.brd]
2025-04-10 Added updated BOM file
    [BOM_ProjectSchematic v42.csv]
2025-04-11 Updated README - partial BOM

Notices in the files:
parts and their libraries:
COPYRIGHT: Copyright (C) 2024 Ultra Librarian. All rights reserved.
